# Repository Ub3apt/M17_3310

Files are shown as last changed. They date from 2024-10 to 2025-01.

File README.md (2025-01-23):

# M17_3310
Mainboard replacement for Nokia 3310

## Photos
Both photos in the `misc` directory are cropped, so that if you scale them for 108mm height, you should be able to make direct measurements using GIMP or other image editing software.

## Firmware
See the example firmware [here](https://github.com/M17-Project/M17_3310-fw).

## Зачем это надо.
Проект позволяет изготовить на фабрике и использовать замаскированый под сотовый телефон компактную радиостанцию работающую по цифровому протоколу М17 с цифровыми ретранляторами, сетями и радиостанциями.  

## Подробное описание на Википедии. 
https://en.wikipedia.org/wiki/M17_(amateur_radio) 

М17 является цифровой режим радиомодуляции разработан Войцехом Качмарским (Wojciech Kaczmarski). M17 в первую очередь предназначен для голосовой связи на УКВ радиолюбителями и прочими.

M17 использует Частота-Разделение Множественный Доступ (FDMA) технология, в которой разные потоки связи разделены по частоте и запускаются одновременно. Он использует 4800 символов в секунду, 4-уровневый частотно-сдвиговая клавиша (4FSK) с а корневой фильтр Найквиста применяется к битовому потоку. Радиоканалы шириной 9 кГц, с интервалом канала 12,5 кГц. валовая скорость передачи данных составляет 9600 бит в секунду, при фактической передаче данных - 3200. Передача, называемая поток, делится на 40-миллисекундную длину кадра, каждая из них дополнена 16-битным длинным словом синхронизации. Группа из 6 кадров образует суперкадр и необходим для декодирования данных информации о ссылках. Протокол позволяет осуществлять низкоскоростную передачу данных (наряду с голосом), например. GNSS данные о положении. Режим успешно передан через EchoStar XXI  и КО-100 геостационарные спутники. Спецификация протокола выпущена под GNU General Public License.

M17 использует Кодек 2низкобитретный голосовой кодек, разработанный Дэвидом Роу VK5DGR и др. Codec 2 был разработан для использования для любительского радио и других голосовых приложений с высокой степенью сжатия. В его основе лежит линейное предсказательное кодирование при смешанно-гармоническом синусоидальном возбуждении. Протокол поддерживает как 3200 (полноценный), так и 1600 бит в секунду (полускоростной) режимы.

Протокол M17 был в первую очередь предназначен для радиолюбительского использования.

  Кодирование Позывного: 48-битное поле, содержащее до 9 буквенно-цифровых символов, устраняет необходимость централизованной базы данных пользовательских ID.
Потоковый и пакетный режимы работы.
Режим потока предлагает один канал с чистым битрейтом 3200 bps (кодированная речь или данные) или два канала с частотой 1600bps (кодированная речь наряду с данными).
Режим пакетов поддерживает обмен текстовыми сообщениями, АПРС и AX.25.
Медленно-скоростной боковой канал для короткой и повторной передачи данных, например. Данные о положении ГНСС или телеметрия.
Шифрование:
Битовое шифрование скремблера: а псевдослучайная двоичная последовательность создан путем объединения эксклюзивно-побочная работа на аудио или потоке данных и сдвиговый регистр с линейной обратной связью используя один из 3 многочлены обратной связи с 255, 65 535 и 16 777 215-битными периодами повторения.
AES шифрование: 128-битный блочный шифр, работающий в режим CTR с выбираемым пользователем ключом 128, 192 или 256 бит.

С небольшой аппаратной модификацией портативные приемопередатчики TYT MD-380, MD-390 и MD-UV380 могут быть оснащены пользовательской бесплатной прошивкой с открытым исходным кодом[12] чтобы включить поддержку M17.

Приложения и проекты с поддержкой M17
OpenRTX - бесплатная прошивка с открытым исходным кодом для ветчинных радиостанций
WPSD - цифровой голосовой программный комплекс для любительского радио персональных точек доступа и ретрансляторов
DroidStar - цифровой голосовой клиент для Android
Многорежимный Цифровой Голосовой Модем (MMDVM)
SDR++ - мультиплатформенный, программно-ориентированный радиоприемник с открытым исходным кодом
SDRangel - мультиплатформенное программное обеспечение с открытым исходным кодом, определяемое радиоприемником/передатчиком
OpenWebRX - веб-программный радиоприемник
отражатель Мрефд - М17[22]
rpitx - общий радиочастотный передатчик для Raspberry Pi[23]
dsd-fme - цифровой декодер речи[24]
mvoice - голосовой клиент и графический ретранслятор (Raspberry и Linux)

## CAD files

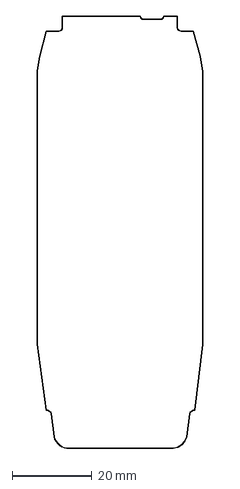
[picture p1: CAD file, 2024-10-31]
misc/3310_outline.dxf
41.4 x 108.0 mm

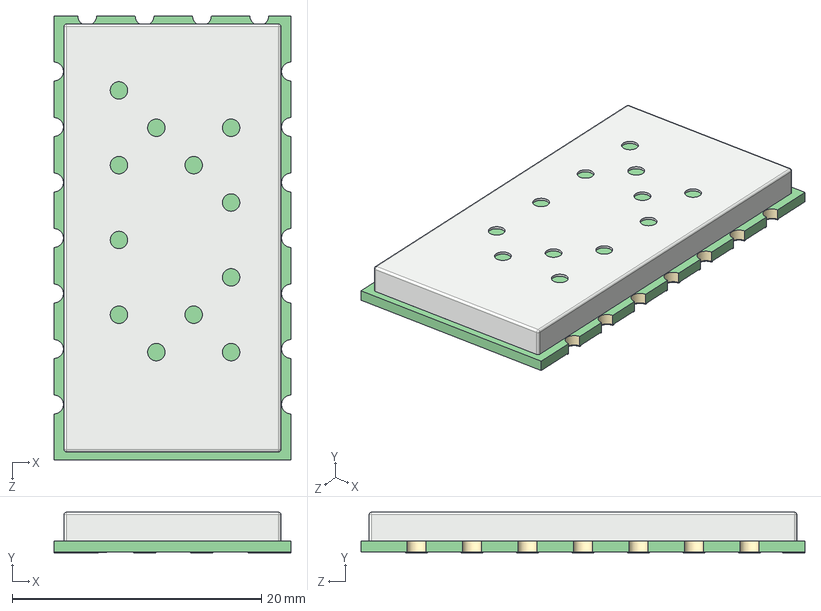
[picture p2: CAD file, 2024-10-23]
models/sa868.step
19.0 x 3.26 x 35.6 mm

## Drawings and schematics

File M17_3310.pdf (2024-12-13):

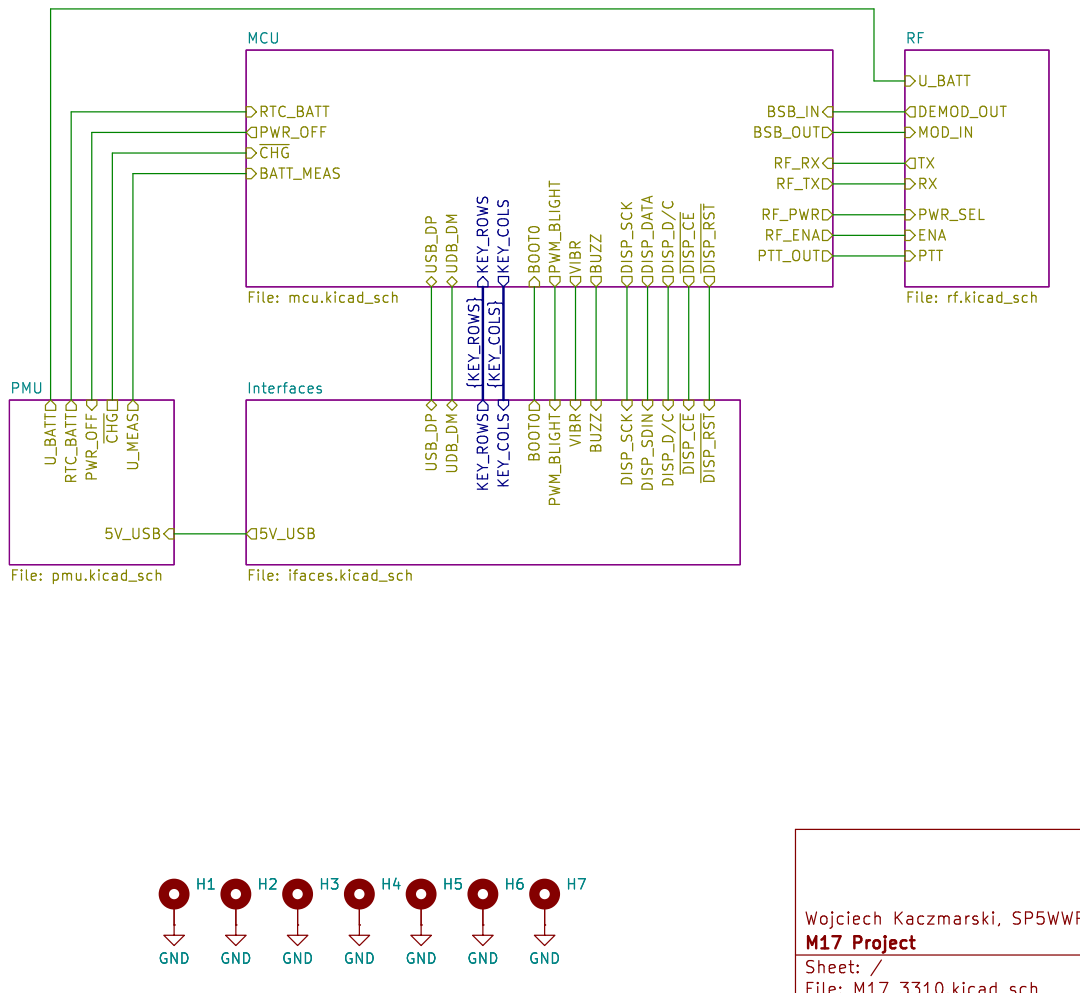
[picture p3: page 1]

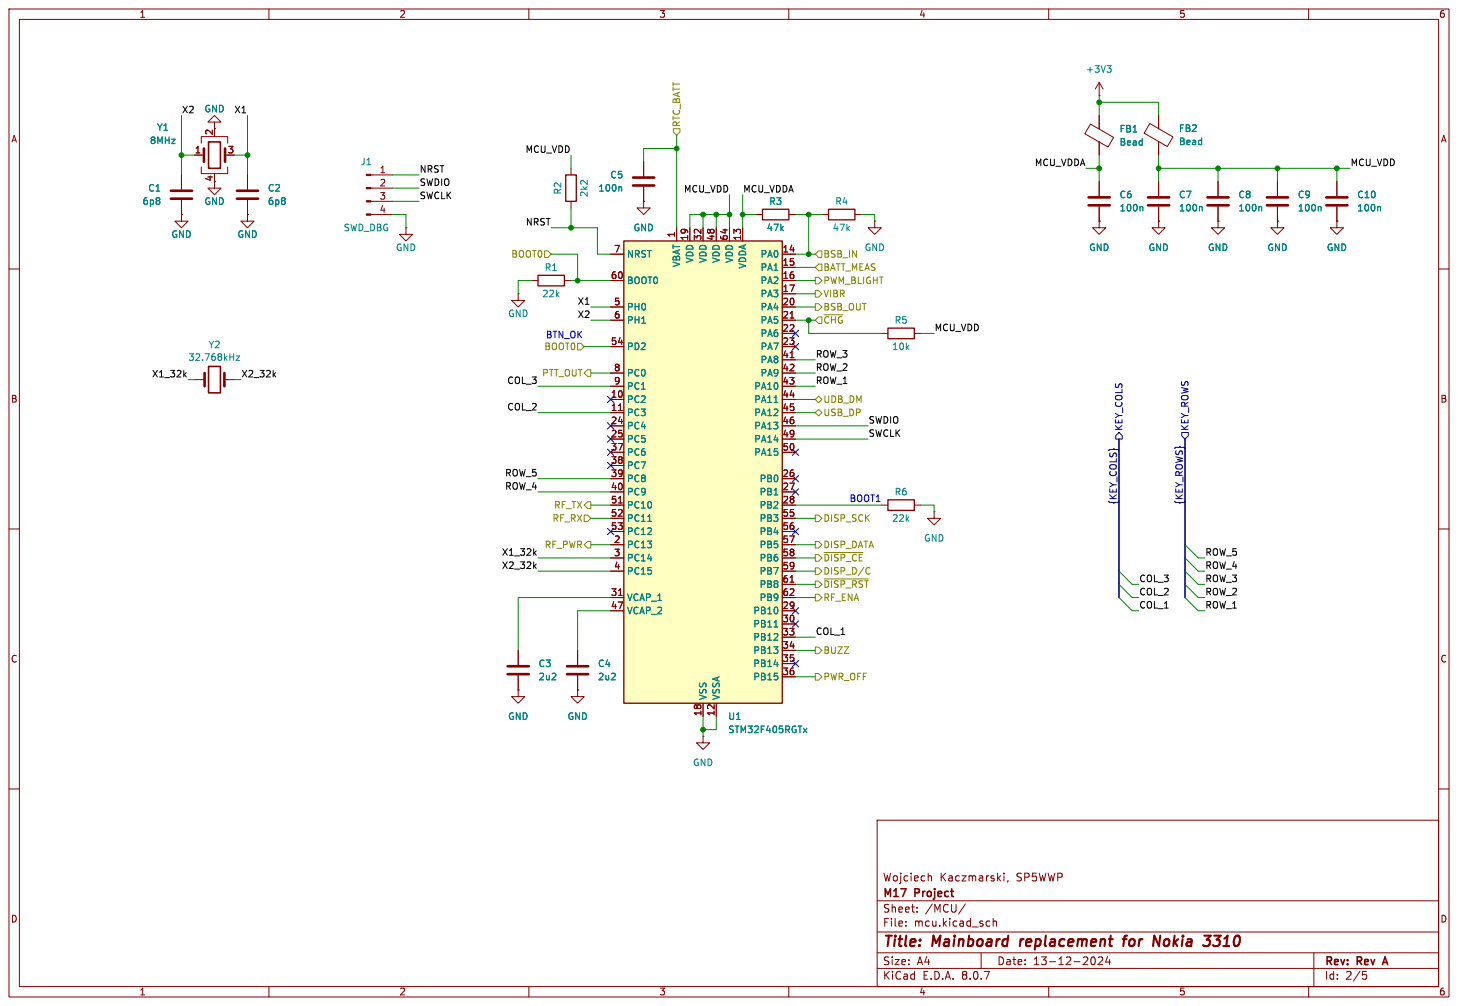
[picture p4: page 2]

1 PC2 10 PC3 11 VSSA 12 VDDA 13 PA0 14 PA1 15 PA2 16 PA3 17 VSS 18 VDD 19 PC13 2 PA4 20 PA5 21 PA6 22 PA7 23 PC4 24 PC5 25 PB0 26 PB1 27 PB2 28 PB10 29 PC14 3 PB11 30 VCAP_1 31 VDD 32 PB12 33 PB13 34 PB14 35 PB15 36 PC6 37 PC7 38 PC8 39 PC15 4 PC9 40 PA8 41 PA9 42 PA10 43 PA11 44 PA12 45 PA13 46 VCAP_2 47 VDD 48 PA14 49 PH0 5 PA15 50 PC10 51 PC11 52 PC12 53 PD2 54 PB3 55 PB4 56 PB5 57 PB6 58 PB7 59 PH1 6 BOOT0 60 PB8 61 PB9 62 VDD 64 NRST 7 PC0 8 PC1 9 C4

1 PC2 10 PC3 11 VSSA 12 VDDA 13 PA0 14 PA1 15 PA2 16 PA3 17 VSS 18 VDD 19 PC13 2 PA4 20 PA5 21 PA6 22 PA7 23 PC4 24 PC5 25 PB0 26 PB1 27 PB2 28 PB10 29 PC14 3 PB11 30 VCAP_1 31 VDD 32 PB12 33 PB13 34 PB14 35 PB15 36 PC6 37 PC7 38 PC8 39 PC15 4 PC9 40 PA8 41 PA9 42 PA10 43 PA11 44 PA12 45 PA13 46 VCAP_2 47 VDD 48 PA14 49 PH0 5 PA15 50 PC10 51 PC11 52 PC12 53 PD2 54 PB3 55 PB4 56 PB5 57 PB6 58 PB7 59 PH1 6 BOOT0 60 PB8 61 PB9 62 VDD 64 NRST 7 PC0 8 PC1 9 U1STM32F405RGTx

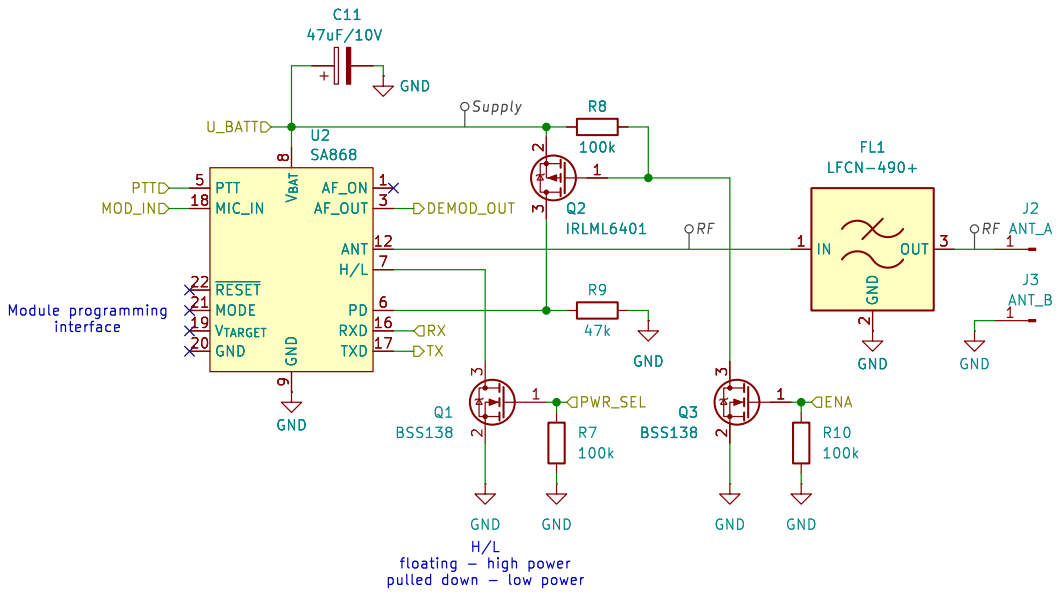
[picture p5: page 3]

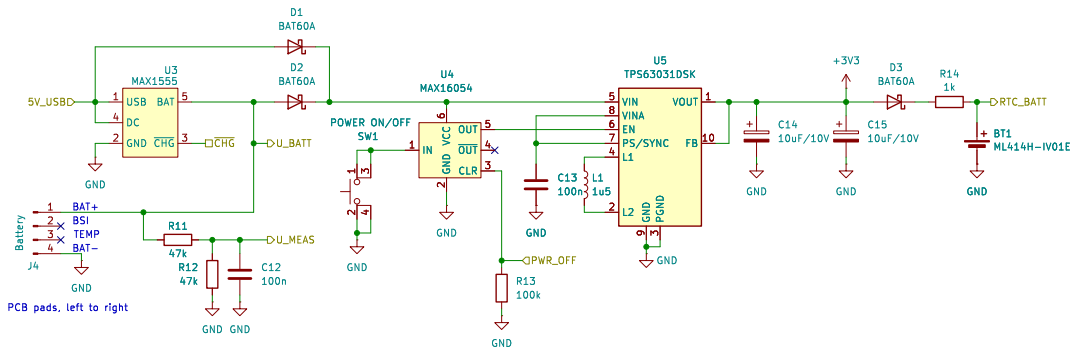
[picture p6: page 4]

2 CLR 3 ~{OUT}4 OUT 5 VCC

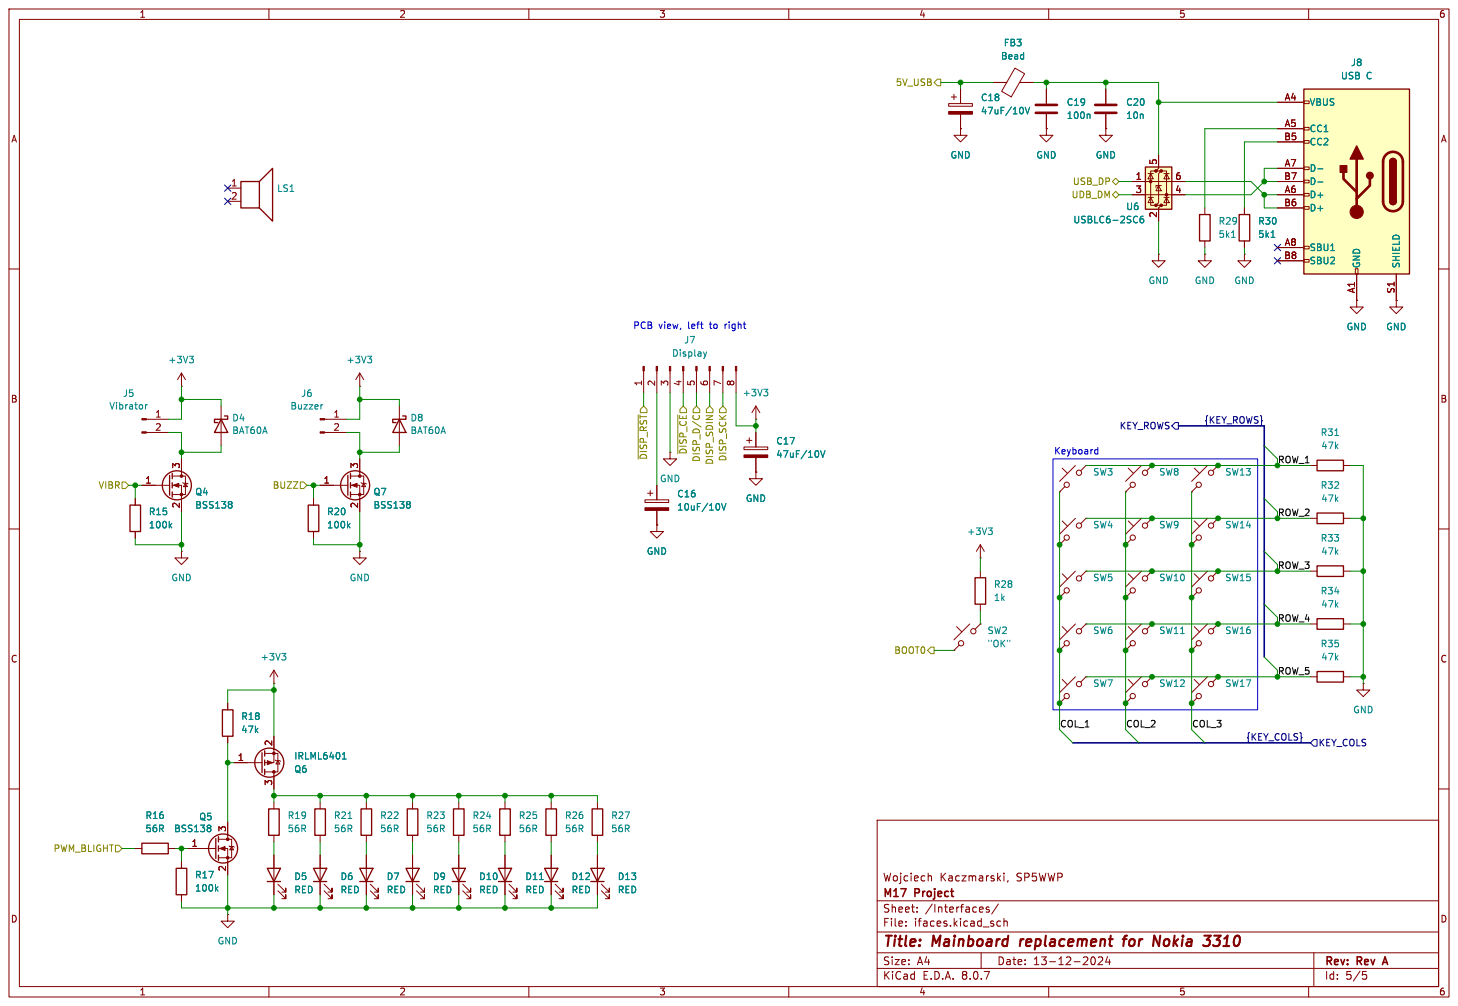
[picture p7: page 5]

{KEY_COLS} PCB view, left to right

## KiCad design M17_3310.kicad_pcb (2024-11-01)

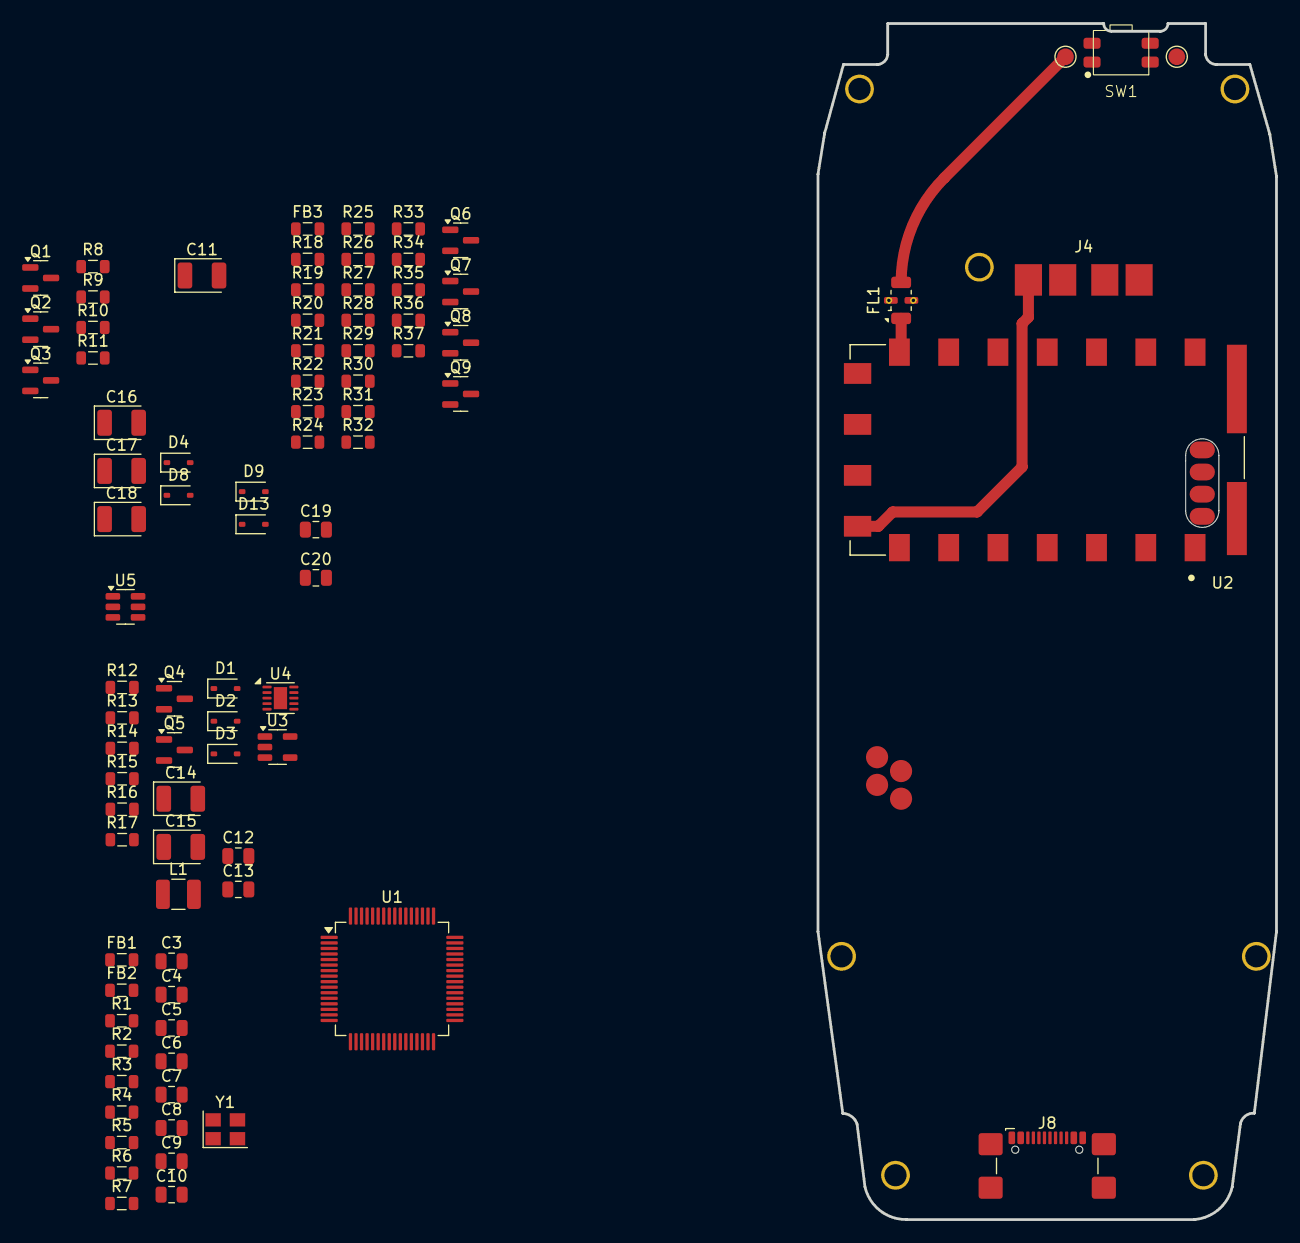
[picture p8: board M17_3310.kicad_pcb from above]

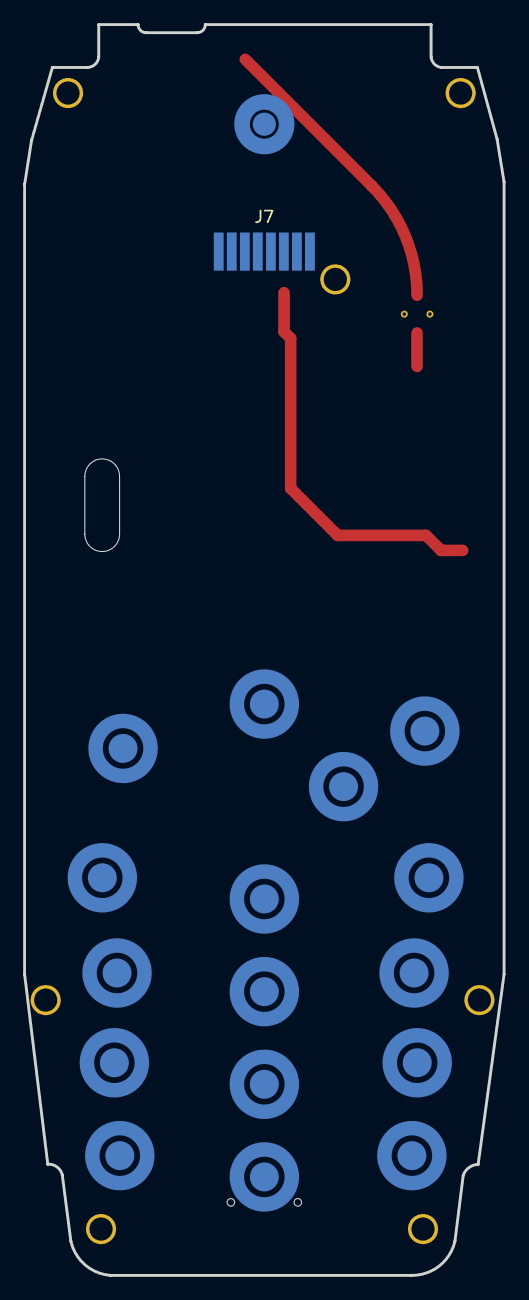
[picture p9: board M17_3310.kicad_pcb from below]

Board: 4 copper layers, 41.4 x 108.0 mm, 113 parts (18 on the bottom side), 66 nets.

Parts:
C3, C4: 2u2; C_0805_2012Metric
C5, C6, C7, C8, C9, C10, C12, C13, C19: 100n; C_0805_2012Metric
C11, C17, C18: 47uF/10V; CP_EIA-3528-21_Kemet-B
C14, C15, C16: 10uF/10V; CP_EIA-3528-21_Kemet-B
C20: 10n; C_0805_2012Metric
D1, D2, D3, D4, D8, D9, D13: BAT60A; D_SOD-323
FB1, FB2, FB3: Bead; L_0805_2012Metric
FL1: LFCN-490+; Filter_Mini-Circuits_FV1206
H1, H2, H3, H4, H5, H6, H7: 2mm_mounting_hole_sig
J1: SWD_DBG; 3310_4_pin
J2: ANT_A; TestPoint_Pad_D1.5mm
J3: ANT_B; TestPoint_Pad_D1.5mm
J4: Battery; 3310_batt
J7: Display; 3310_display
J8: USB C; USB_C_Receptacle_GCT_USB4110
L1: 1u5; L_1210_3225Metric
LS1: 3310_speaker
Q1, Q3, Q4, Q6, Q7, Q9: BSS138; SOT-23
Q2, Q8: IRLML6401; SOT-23
Q5: BSS84; SOT-23
R1, R5: 22k; L_0805_2012Metric
R2: 2k2; L_0805_2012Metric
R3, R4, R9, R11, R12, R15, R20, R33, R34, R35, R36, R37: 47k; L_0805_2012Metric
R6: 10k; L_0805_2012Metric
R7, R8, R10, R13, R14, R17, R19, R22: 100k; L_0805_2012Metric
R16, R30: 1k; L_0805_2012Metric
R18: 47R; L_0805_2012Metric
R21, R23, R24, R25, R26, R27, R28, R29: 27R; L_0805_2012Metric
R31, R32: 5k1; L_0805_2012Metric
SW1: POWER ON; SIDE PUSH 2.2NF 4.7x3.2x1.65mm
SW2: "OK"; 3310_key
SW3, SW4, SW5, SW6, SW7, SW8, SW9, SW10, SW11, SW12, SW13, SW14, SW15, SW16, SW17: 3310_key
U1: STM32F405RGTx; LQFP-64_10x10mm_P0.5mm
U2: SA868; SA868-VER1.1
U3: MAX1555; TSOT-23-5
U4: TPS63030DSK; WSON-10-1EP_2.5x2.5mm_P0.5mm_EP1.2x2mm
U5: USBLC6-2SC6; SOT-23-6
Y1: 8MHz; Crystal_SMD_3225-4Pin_3.2x2.5mm

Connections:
+3V3: C14.1, C15.1, C17.1, D3.2 (A), D4.1 (K), D8.1 (K), D9.1 (K), D13.1 (K), FB1.2, FB2.1, J7.8, Q8.2 (S), R6.1, R20.2, R30.2, U4.1 (VOUT), U4.10 (FB)
/COL_1: SW3.1, SW4.1, SW5.1, SW6.1, SW7.1
/COL_2: SW8.1, SW9.1, SW10.1, SW11.1, SW12.1
/COL_3: SW13.1, SW14.1, SW15.1, SW16.1, SW17.1
/Interfaces/5V_USB: C18.1, D1.2 (A), FB3.1, U3.1 (USB), U3.4 (DC)
/Interfaces/BOOT0: R1.1, SW2.1, U1.60 (BOOT0)
/Interfaces/BUZZ: Q9.1 (G), R22.2
/Interfaces/DISP_D/C: J7.5, U1.59 (PB7)
/Interfaces/DISP_SCK: J7.7, U1.55 (PB3)
/Interfaces/DISP_SDIN: J7.6, U1.57 (PB5)
/Interfaces/UDB_DM: U1.44 (PA11), U5.1 (I/O1)
/Interfaces/USB_DP: U1.45 (PA12), U5.3 (I/O2)
/Interfaces/VIBR: Q6.1 (G), R17.2
/Interfaces/~DISP_CE: J7.4, U1.58 (PB6)
/Interfaces/~DISP_RST: J7.1, U1.61 (PB8)
/MCU/BATT_MEAS: C12.2, R11.1, R12.2, U1.15 (PA1)
/MCU/BSB_IN: R3.1, R4.2, U1.14 (PA0), U2.3 (AF_OUT)
/MCU/BSB_OUT: U1.20 (PA4), U2.18 (MIC_IN)
/MCU/MCU_VDD: C7.1, C8.1, C9.1, C10.1, FB2.2, R2.1, U1.19 (VDD), U1.32 (VDD), U1.48 (VDD), U1.64 (VDD)
/MCU/MCU_VDDA: C6.2, FB1.1, R3.2, U1.13 (VDDA)
/MCU/NRST: J1.1, R2.2, U1.7 (NRST)
/MCU/PWR_ON: Q4.1 (G), R14.2, U1.36 (PB15)
/MCU/RF_ENA: Q3.1 (G), R10.2
/MCU/RF_PWR: Q1.1 (G), R7.2
/MCU/RTC_BATT: C5.2, R16.1, U1.1 (VBAT)
/MCU/SWCLK: J1.3, U1.49 (PA14)
/MCU/SWDIO: J1.2, U1.46 (PA13)
/MCU/X1: U1.5 (PH0), Y1.1
/MCU/X2: U1.6 (PH1), Y1.3
/MCU/~CHG: R6.2, U1.35 (PB14), U3.3 (~CHG)
/PMU/U_BATT: C11.1, D2.2 (A), J4.1, Q2.2 (S), R8.2, R11.2, U2.8 (V_{BAT}), U3.5 (BAT)
/ROW_1: R33.2, SW3.2, SW8.2, SW13.2
/ROW_2: R34.2, SW4.2, SW9.2, SW14.2
/ROW_3: R35.2, SW5.2, SW10.2, SW15.2
/ROW_4: R36.2, SW6.2, SW11.2, SW16.2
/ROW_5: R37.2, SW7.2, SW12.2, SW17.2
GND: C3.1, C4.1, C5.1, C6.1, C7.2, C8.2, C9.2, C10.2, C11.2, C12.1, C13.1, C14.2, C15.2, C16.2, C17.2, C18.2, C19.2, C20.2, FL1.2 (GND), FL1.4 (GND), H1.1, H2.1, H3.1, H4.1, H5.1, H6.1, H7.1, J1.4, J3.1, J4.4, J7.3, J8.A1 (GND), J8.A12 (GND), J8.B1 (GND), J8.B12 (GND), J8.S1 (SHIELD), Q1.2 (S), Q3.2 (S), Q4.2 (S), Q6.2 (S), Q7.2 (S), Q9.2 (S), R1.2, R4.1, R5.1, R7.1, R9.1, R10.1, R12.1, R14.1, R15.1, R17.1, R19.1, R22.1, R31.2, R32.2, R33.1, R34.1, R35.1, R36.1, R37.1, U1.12 (VSSA), U1.18 (VSS), U1.63 (VSS), U2.9 (GND), U2.10 (GND), U3.2 (GND), U4.3 (PGND), U4.9 (GND), U4.11 (PGND), U5.2 (GND), Y1.2, Y1.4
unnamed: D1.1 (K), D2.1 (K), Q5.2 (S), R13.2, SW1.2, SW1.4 (A), U4.5 (VIN)
unnamed: D3.1 (K), R16.2
unnamed: D4.2 (A), Q6.3 (D)
unnamed: D8.2 (A), Q9.3 (D)
unnamed: D9.2 (A), R25.2
unnamed: D13.2 (A), R29.2
unnamed: FL1.1 (IN), U2.12 (ANT)
unnamed: FL1.3 (OUT), J2.1
unnamed: C16.1, J7.2
unnamed: J8.A5 (CC1), R31.1
unnamed: J8.B5 (CC2), R32.1
unnamed: J8.A6 (D+), J8.B6 (D+), U5.4 (I/O2)
unnamed: J8.A7 (D-), J8.B7 (D-), U5.6 (I/O1)
unnamed: Q1.3 (D), U2.7 (H/L)
unnamed: Q2.3 (D), R9.2, U2.6 (PD)
unnamed: Q2.1 (G), Q3.3 (D), R8.1
unnamed: Q4.3 (D), Q5.1 (G), R13.1
unnamed: Q5.3 (D), R15.2, SW1.1, SW1.3 (K), U4.6 (EN)
unnamed: Q7.3 (D), Q8.1 (G), R20.1
unnamed: Q7.1 (G), R18.2, R19.2
unnamed: Q8.3 (D), R21.1, R23.1, R24.1, R25.1, R26.1, R27.1, R28.1, R29.1
unnamed: R30.1, SW2.2
unnamed: R5.2, U1.28 (PB2)
unnamed: C3.2, U1.31 (VCAP_1)
unnamed: C4.2, U1.47 (VCAP_2)
unnamed: L1.1, U4.4 (L1)
unnamed: L1.2, U4.2 (L2)
unnamed: C13.2, U4.7 (PS/SYNC), U4.8 (VINA)
unnamed: C19.1, C20.1, FB3.2, J8.A4 (VBUS), J8.A9 (VBUS), J8.B4 (VBUS), J8.B9 (VBUS), U5.5 (VBUS)

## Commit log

2024-10-21 first push
    [M17_3310.kicad_pcb, M17_3310.kicad_sch, ifaces.kicad_sch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]
2024-10-21 more stuff
    [ifaces.kicad_sch, mcu.kicad_sch, pmu.kicad_sch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]
2024-10-23 imported SA868 - thanks, edgetriggered
    [M17_3310.kicad_sch, ifaces.kicad_sch, mcu.kicad_sch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]
2024-10-24 interfaces update
    [M17_3310.kicad_sch, ifaces.kicad_sch, mcu.kicad_sch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]
2024-10-25 RF module footprint update
    [mcu.kicad_sch]
2024-10-25 audio part
    [M17_3310.kicad_sch, audio.kicad_sch, filters.kicad_sch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]
2024-10-28 spk/mic update
    [M17_3310.kicad_sch, audio.kicad_sch, filters.kicad_sch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]
2024-10-31 removed audio part
    - added buzzer
    - added battery voltage measurement
    [M17_3310.kicad_sch, audio.kicad_sch, filters.kicad_sch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]
2024-10-31 mayhem
    - removed sd card slot
    - started pcb design
    - added nice 3310 photos
    [3310_outline.dxf, M17_3310.kicad_pcb, M17_3310.kicad_sch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]
2024-10-31 USB C receptacle's PN update
    [ifaces.kicad_sch]
2024-10-31 added vibro+buzzer footprints
2024-11-01 keypad in place
    [M17_3310.kicad_pcb]
2024-11-01 some pcb updates
    - linked vibrator/buzzer footprints
    [ifaces.kicad_sch]
2024-11-02 pcb update
    [M17_3310.kicad_sch, ifaces.kicad_sch, mcu.kicad_sch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]
2024-11-02 more pcb routing
    [ifaces.kicad_sch, mcu.kicad_sch, pmu.kicad_sch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]
2024-11-05 routed BTN_OK
    [mcu.kicad_sch]
2024-11-22 PCB update
    - added GND vias
2024-11-22 gitignore update
    - ignore zip files generated by pcbway-plugin
2024-11-22 PN update
    [M17_3310.kicad_sch, ifaces.kicad_sch, mcu.kicad_sch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]
2024-11-22 "no connection" tags
    [M17_3310.kicad_sch, ifaces.kicad_sch, mcu.kicad_sch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]
2024-11-23 fixed DNP tags
    [M17_3310.kicad_sch, ifaces.kicad_sch, mcu.kicad_sch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]
2024-12-13 U5 value update
    TPS63030 is a regulated version of the 3.3V TPS63031. The latter is correct.
    [M17_3310.kicad_sch, ifaces.kicad_sch, mcu.kicad_sch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]
2025-01-23 Update README.md
    Дополнение к описанию проекта
